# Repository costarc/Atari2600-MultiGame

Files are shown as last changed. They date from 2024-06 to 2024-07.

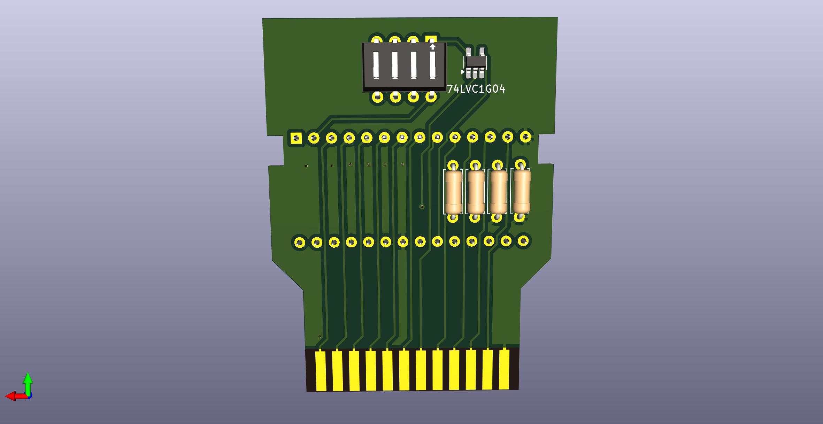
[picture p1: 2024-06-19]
Atari2600MultiGame_b.jpg

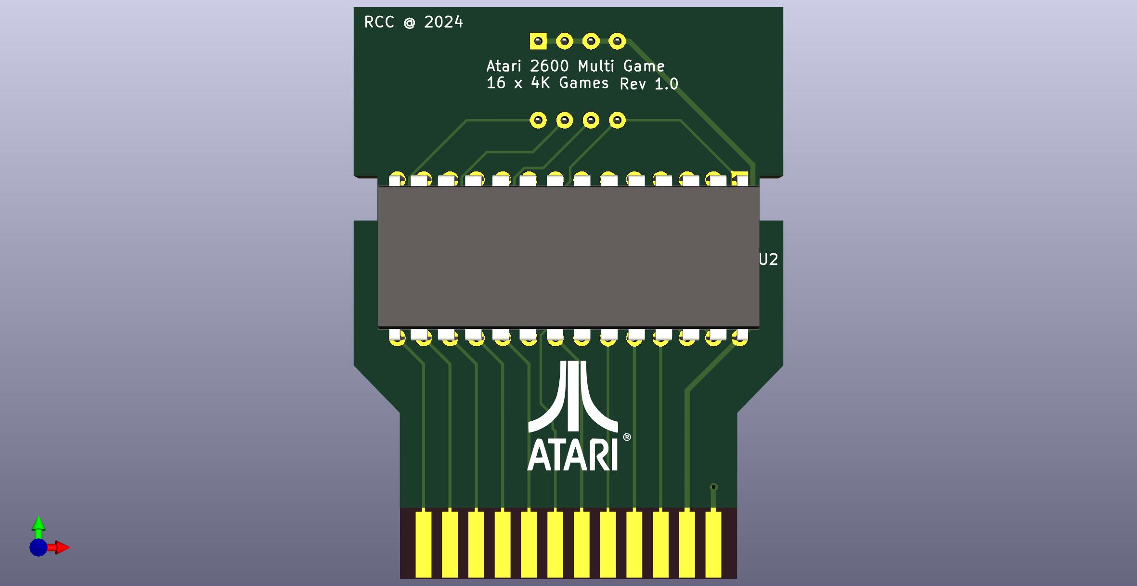
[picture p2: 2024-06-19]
Atari2600MultiGame.jpg

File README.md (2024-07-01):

# Atari 2600 MultiGame Cartridge

Bill of material
--
Bill of Material is in interactive mode - click on file https://github.com/costarc/Atari2600-MultiGame/blob/master/ibom.html (you may need to download to your local computer to see it properly)

# Description

This cartridge supports 2K and 4K games.
2K games must be 4K as well (two copies of the same file appended). For example, the followign two commands will (compatible with Mac OS, Linux and CygWin in windows) will create a 4kgame.bin file with two copies of the same 2kgame.bin:<br>
<code>
cat 2kgame.bin >  4kgame.bin<br>
cat 2kgame.bin >> 4kgame.bin<br>
</code>
<br>
The PCB supports 27C512 ROMs and EPROMS and can hold up to 16 games, switchable via the DIP Switch at the back of the cartridge.

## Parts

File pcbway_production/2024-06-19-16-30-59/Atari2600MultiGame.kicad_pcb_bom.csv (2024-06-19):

designator | quantity | value | pack | mpn | mount_type
J1 | 1 | 2600_Cartridge_Port | 2600_Cartridge_Port |  | tht
R1, R2, R3, R4 | 4 | 10K | R_Axial_DIN0207_L6.3mm_D2.5mm_P7.62mm_Horizontal |  | tht
SW1 | 1 | SW_DIP_x04 | SW_DIP_SPSTx04_Slide_6.7x11.72mm_W7.62mm_P2.54mm_LowProfile |  | tht
U2 | 1 | 27C512 | DIP-28_W15.24mm |  | tht
U3 | 1 | 74LVC1G04 | SOT-23-5_HandSoldering |  | smt

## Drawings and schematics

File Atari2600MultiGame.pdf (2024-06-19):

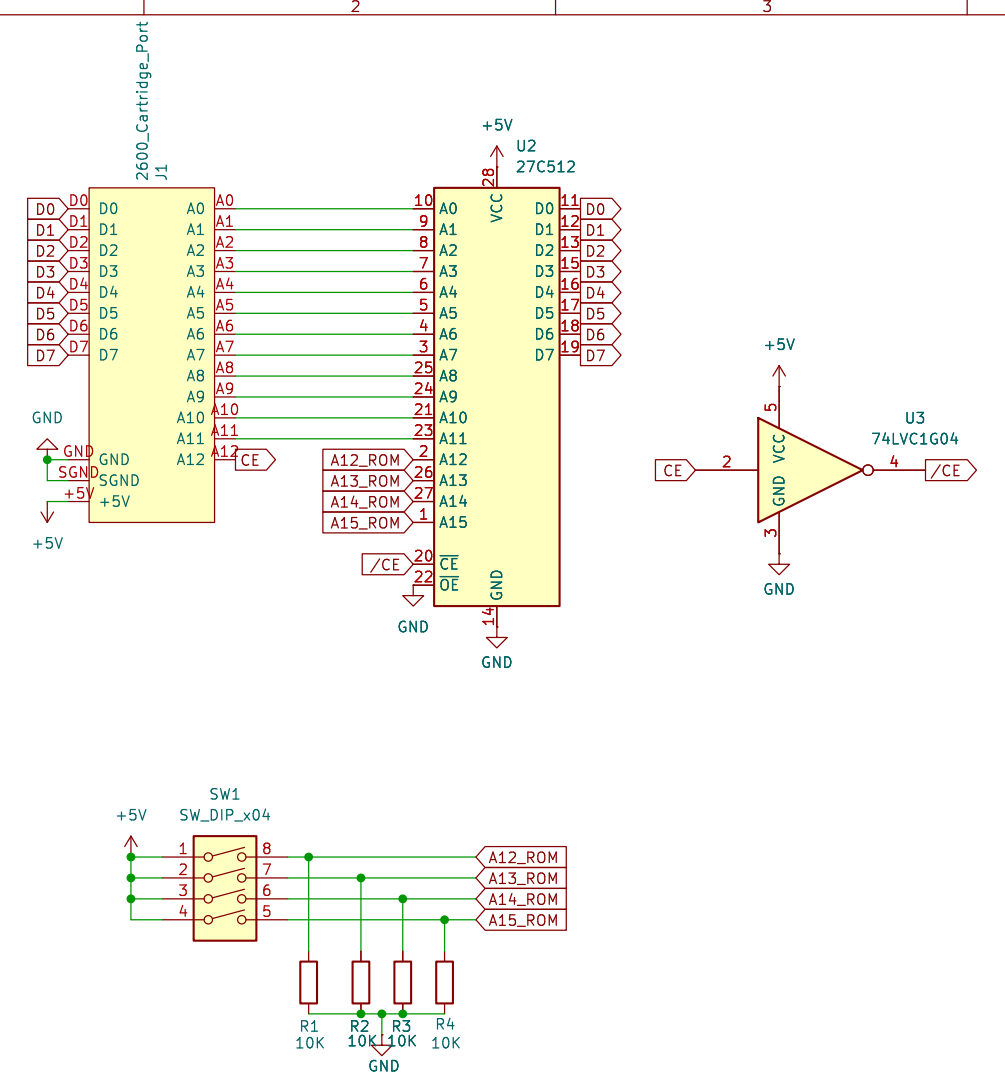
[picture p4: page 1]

Id: 1/1 Title: Atari 2600 Muti Game

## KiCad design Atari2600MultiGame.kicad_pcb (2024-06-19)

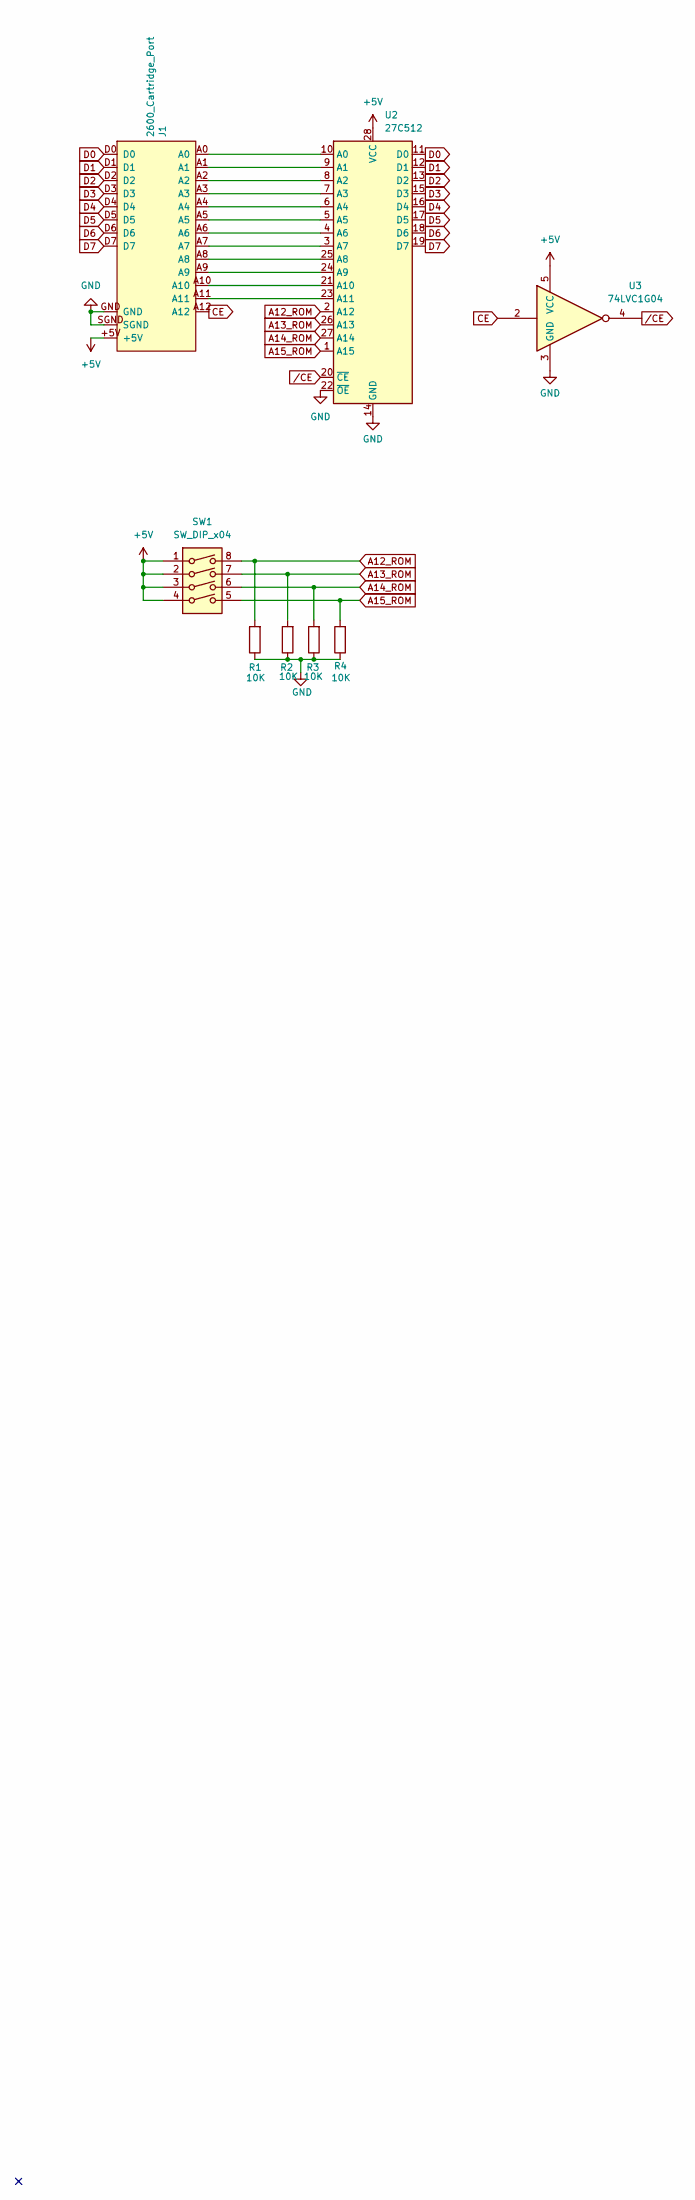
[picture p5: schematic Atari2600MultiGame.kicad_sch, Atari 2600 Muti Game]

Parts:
J1: 2600_Cartridge_Port
R1, R2, R3, R4: 10K; R_Axial_DIN0207_L6.3mm_D2.5mm_P7.62mm_Horizontal
SW1: SW_DIP_x04; SW_DIP_SPSTx04_Slide_6.7x11.72mm_W7.62mm_P2.54mm_LowProfile
U2: 27C512; DIP-28_W15.24mm
U3: 74LVC1G04; SOT-23-5_HandSoldering

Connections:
+5V: J1.+5V, SW1.1, SW1.2, SW1.3, SW1.4, U2.28 (VCC), U3.5 (VCC)
A12_ROM: R1.2, SW1.8, U2.2 (A12)
A13_ROM: R2.2, SW1.7, U2.26 (A13)
A14_ROM: R3.2, SW1.6, U2.27 (A14)
A15_ROM: R4.2, SW1.5, U2.1 (A15)
CE: J1.A12, U3.2
D0: J1.D0, U2.11 (D0)
D1: J1.D1, U2.12 (D1)
D2: J1.D2, U2.13 (D2)
D3: J1.D3, U2.15 (D3)
D4: J1.D4, U2.16 (D4)
D5: J1.D5, U2.17 (D5)
D6: J1.D6, U2.18 (D6)
D7: J1.D7, U2.19 (D7)
GND: J1.GND, J1.SGND, R1.1, R2.1, R3.1, R4.1, U2.14 (GND), U2.22 (~OE), U3.3 (GND)
unnamed: J1.A0, U2.10 (A0)
unnamed: J1.A1, U2.9 (A1)
unnamed: J1.A2, U2.8 (A2)
unnamed: J1.A3, U2.7 (A3)
unnamed: J1.A4, U2.6 (A4)
unnamed: J1.A5, U2.5 (A5)
unnamed: J1.A6, U2.4 (A6)
unnamed: J1.A7, U2.3 (A7)
unnamed: J1.A8, U2.25 (A8)
unnamed: J1.A9, U2.24 (A9)
unnamed: J1.A10, U2.21 (A10)
unnamed: J1.A11, U2.23 (A11)
/CE: U2.20 (~CE), U3.4

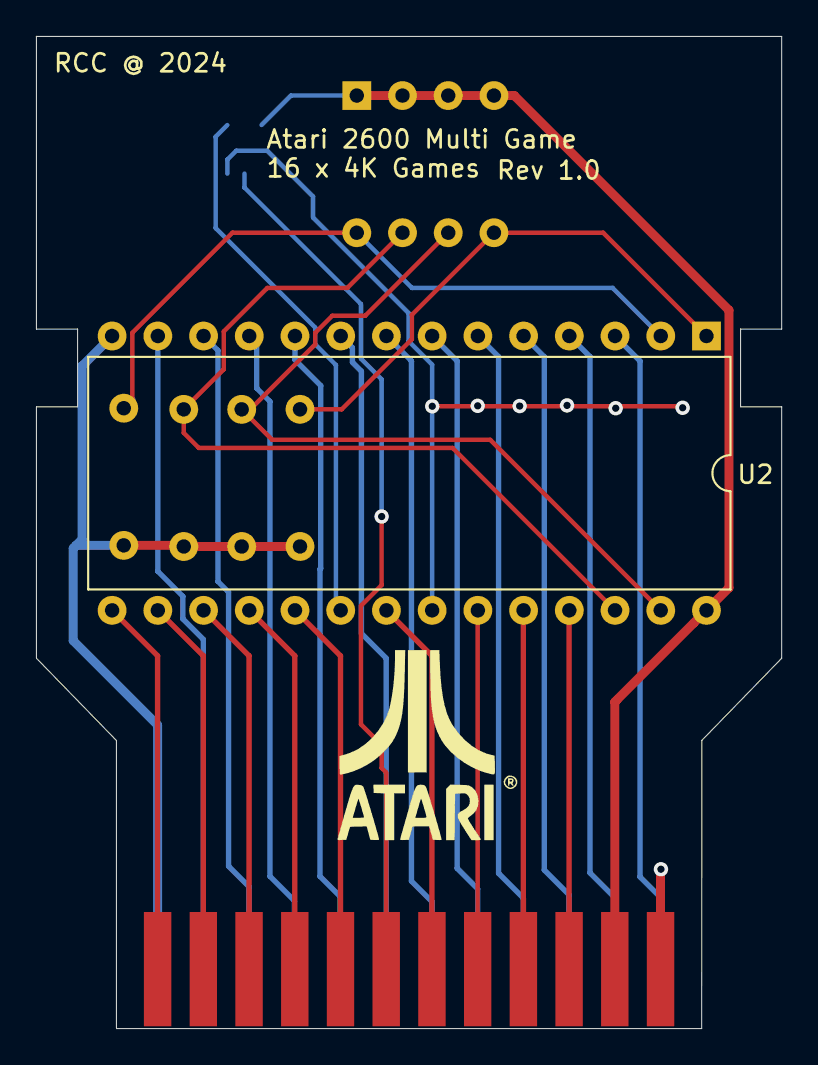
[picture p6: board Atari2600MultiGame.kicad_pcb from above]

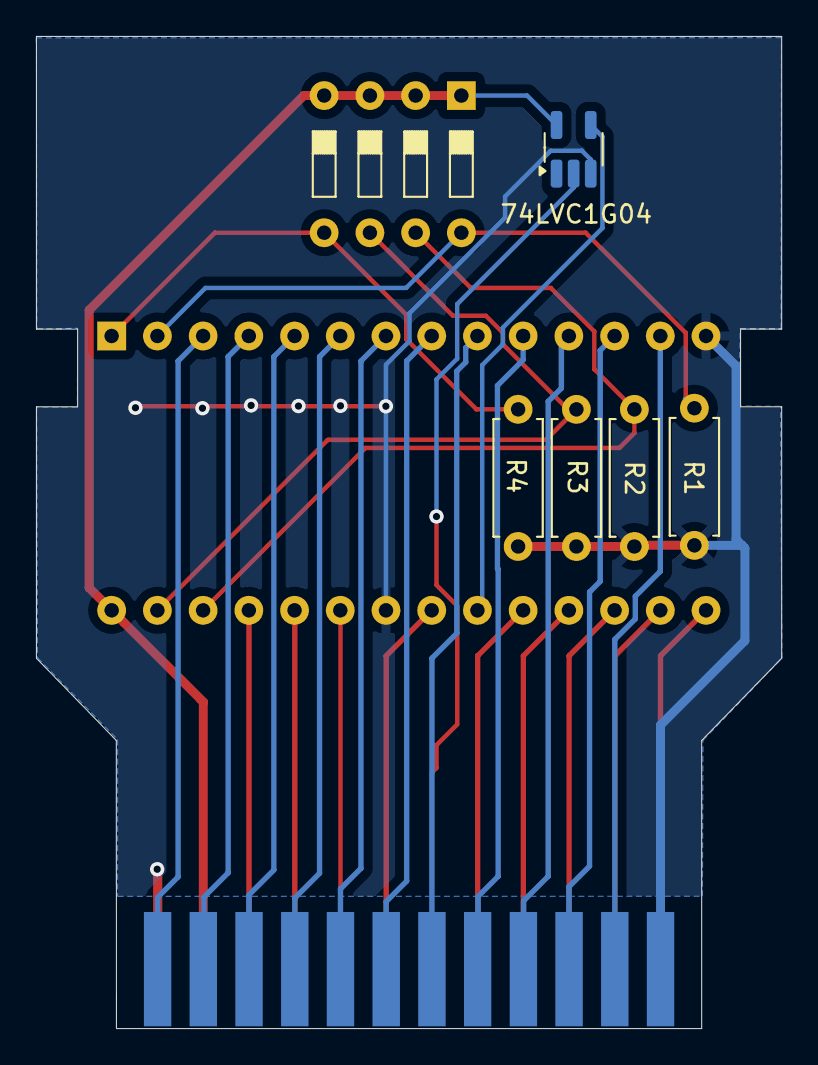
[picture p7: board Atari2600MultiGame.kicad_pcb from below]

Board: 2 copper layers, 41.4 x 55.1 mm, 8 parts (6 on the bottom side), 28 nets.
